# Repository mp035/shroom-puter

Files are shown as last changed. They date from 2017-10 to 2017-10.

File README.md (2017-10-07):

# shroom-puter
A climate controller for a peltier cooled fruting chamber for mushrooms and other cultures.

This is a personal project so it is not as polished as it could be.

It is based on a Nucleo STM32 Nucleo L031-K6 development board (RS Components part# 9173781)  Other suppliers can be found on [octopart](https://octopart.com/search?q=NUCLEO-L031)

The temperature and humidity sensor is an SHT10.  I found that only the soil temperature and humidity sensors would handle the high humidity environment present inside the chamber.  I got mine on ebay, similar to this one: [Link to eBay page](http://www.ebay.com.au/itm/1-PCS-Temperature-Humidity-Sensor-Soil-sensor-with-SHT10-Sensor-Probe-NEW-/222600539398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)

The LCD is a Nokia 3310/5510 on a breakout board similar to this one: [Link to eBay page](http://www.ebay.com.au/itm/1PCS-84-48-84x48-LCD-Module-White-Backlight-Adapter-PCB-for-Nokia-5110-Arduino-/152131918753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)

The PCB layout is done in Eagle.  I have a newer version in KiCad in the works, but the firmware has not yet been altered to work with the new design.

The sofware is developed with System Workbench for STM32 (sw4stm32) you can use the on-board debugger on the Nucleo to program the firmware.

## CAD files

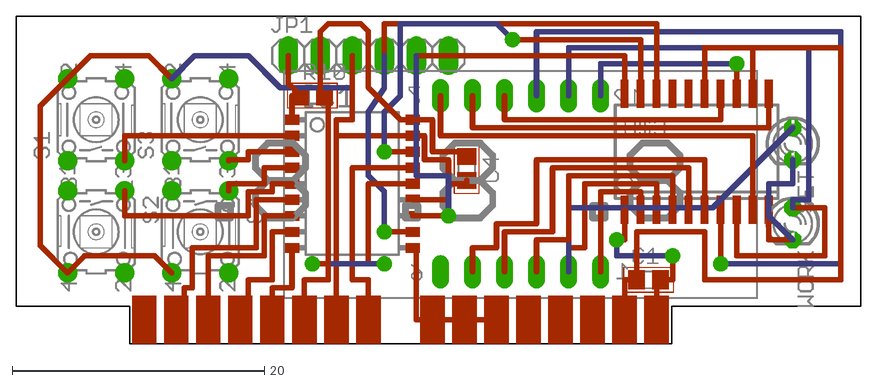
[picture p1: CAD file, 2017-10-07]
eagle_pcb/temperature_controller.dxf
67.0 x 26.0

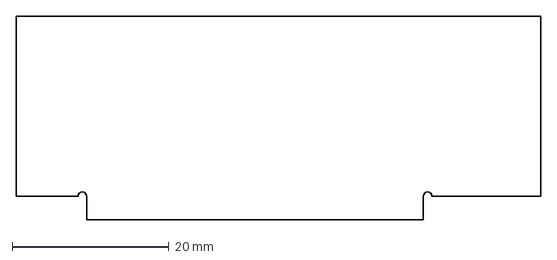
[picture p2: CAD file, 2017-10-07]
eagle_pcb/temperature_controller_top_outline.dxf
67.0 x 26.0 mm

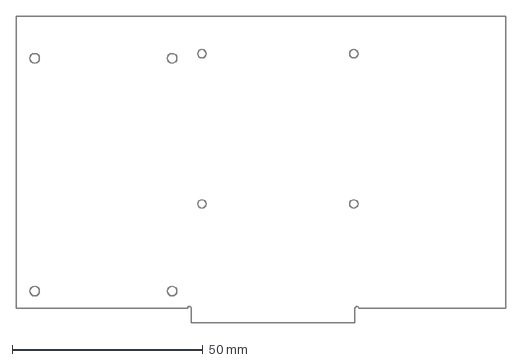
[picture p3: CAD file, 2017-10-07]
eagle_pcb/climate_control_outline.dxf
128.2 x 80.4 mm

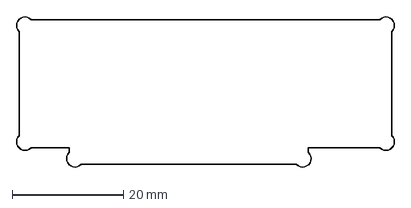
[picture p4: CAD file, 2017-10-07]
eagle_pcb/temperature_controller_top_pocket.dxf
68.2 x 27.2 mm

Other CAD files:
eagle_pcb/.AppleDouble/temperature_controller.dxf
eagle_pcb/.AppleDouble/temperature_controller_top_outline.dxf
eagle_pcb/.AppleDouble/climate_control.dxf
eagle_pcb/.AppleDouble/temperature_controller_top_pocket.dxf
eagle_pcb/.AppleDouble/temperature_controller_bottom_pocket.dxf
eagle_pcb/.AppleDouble/climate_control_outline.dxf

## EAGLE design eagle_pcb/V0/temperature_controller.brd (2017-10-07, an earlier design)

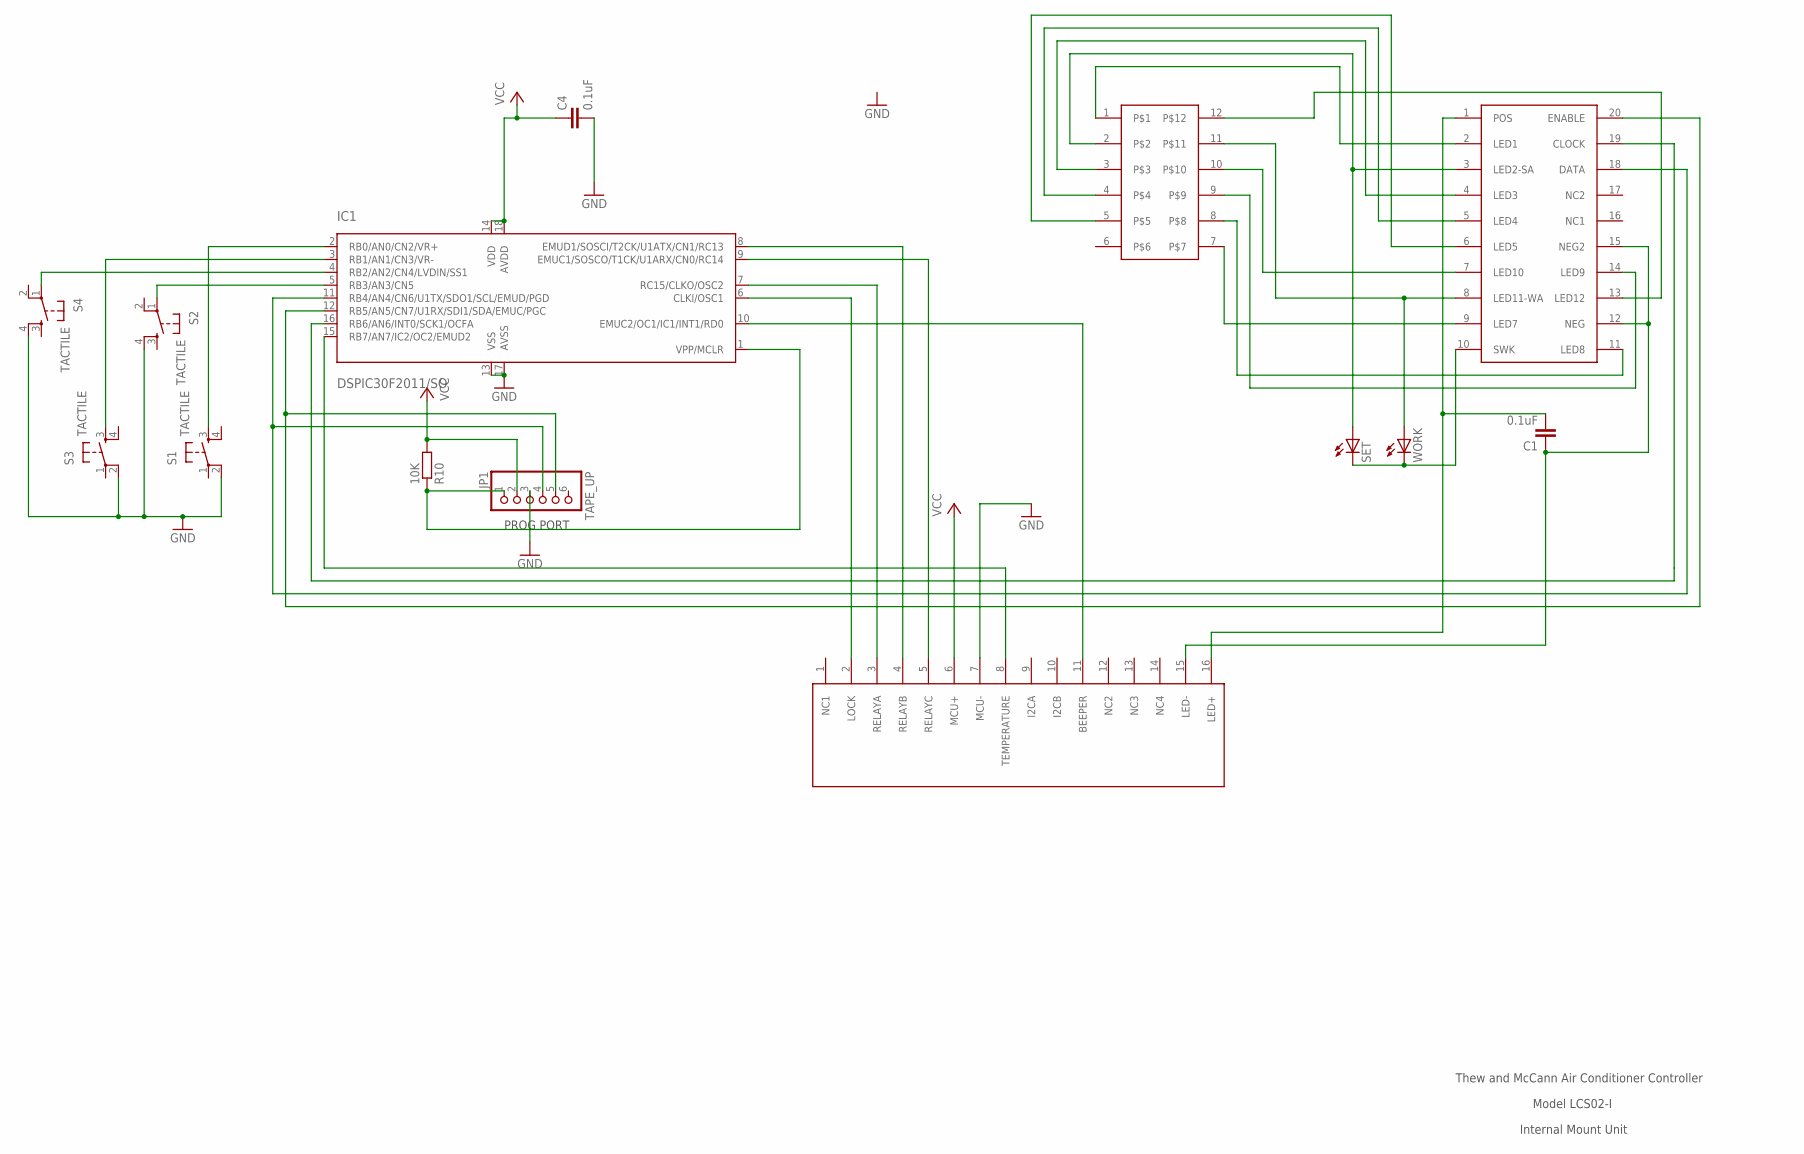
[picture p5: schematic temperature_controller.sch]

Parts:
C1, C4: 0.1uF; C0805
IC1: DSPIC30F2011/SO; SO-18W
JP1: TAPE_UP; 1X06
R10: 10K; R0805
S1, S2, S3, S4: TACTILE
SET: LED3MM
U$1: 3_DIGIT_LED
U$2: WILLHI_EDGE
U$3: 3_DIGIT_DRIVER; SO20W
WORK: LED3MM

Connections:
GND: C4.2, IC1.13 (VSS), IC1.17 (AVSS), JP1.3, S1.2 (P1), S2.4 (S1), S3.2 (P1), S4.4 (S1), U$2.7 (MCU-)
unnamed: U$1.1, U$3.2 (LED1)
unnamed: IC1.4 (RB2/AN2/CN4/LVDIN/SS1), S4.1
unnamed: SET.A, U$1.2, U$3.3 (LED2-SA)
unnamed: U$1.3, U$3.4 (LED3)
unnamed: U$1.4, U$3.5 (LED4)
unnamed: U$1.5, U$3.6 (LED5)
unnamed: U$1.10, U$3.7 (LED10)
unnamed: U$1.11, U$3.8 (LED11-WA), WORK.A
unnamed: U$1.7, U$3.9 (LED7)
unnamed: U$1.9, U$3.14 (LED9)
unnamed: U$1.8, U$3.11 (LED8)
unnamed: SET.K (C), U$3.10 (SWK), WORK.K (C)
unnamed: U$1.12, U$3.13 (LED12)
unnamed: IC1.11 (RB4/AN4/CN6/U1TX/SDO1/SCL/EMUD/PGD), JP1.4, U$3.18 (DATA)
unnamed: IC1.5 (RB3/AN3/CN5), S2.1
unnamed: IC1.16 (RB6/AN6/INT0/SCK1/OCFA), U$3.19 (CLOCK)
unnamed: IC1.7 (RC15/CLKO/OSC2), U$2.3 (RELAYA)
unnamed: IC1.15 (RB7/AN7/IC2/OC2/EMUD2), U$2.8 (TEMPERATURE)
unnamed: C1.2, U$2.16 (LED+), U$3.1 (POS)
unnamed: IC1.1 (VPP/MCLR), JP1.1, R10.1
unnamed: C1.1, U$2.15 (LED-), U$3.12 (NEG), U$3.15 (NEG2)
unnamed: IC1.8 (EMUD1/SOSCI/T2CK/U1ATX/CN1/RC13), U$2.4 (RELAYB)
unnamed: IC1.6 (CLKI/OSC1), U$2.2 (LOCK)
unnamed: IC1.9 (EMUC1/SOSCO/T1CK/U1ARX/CN0/RC14), U$2.5 (RELAYC)
unnamed: IC1.10 (EMUC2/OC1/IC1/INT1/RD0), U$2.11 (BEEPER)
unnamed: IC1.3 (RB1/AN1/CN3/VR-), S3.3 (S)
unnamed: IC1.12 (RB5/AN5/CN7/U1RX/SDI1/SDA/EMUC/PGC), JP1.5, U$3.20 (ENABLE)
unnamed: IC1.2 (RB0/AN0/CN2/VR+), S1.3 (S)
VCC: C4.1, IC1.14 (VDD), IC1.18 (AVDD), JP1.2, R10.2, U$2.6 (MCU+)

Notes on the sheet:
PROG PORT
Thew and McCann Air Conditioner Controller
Model LCS02-I
Internal Mount Unit

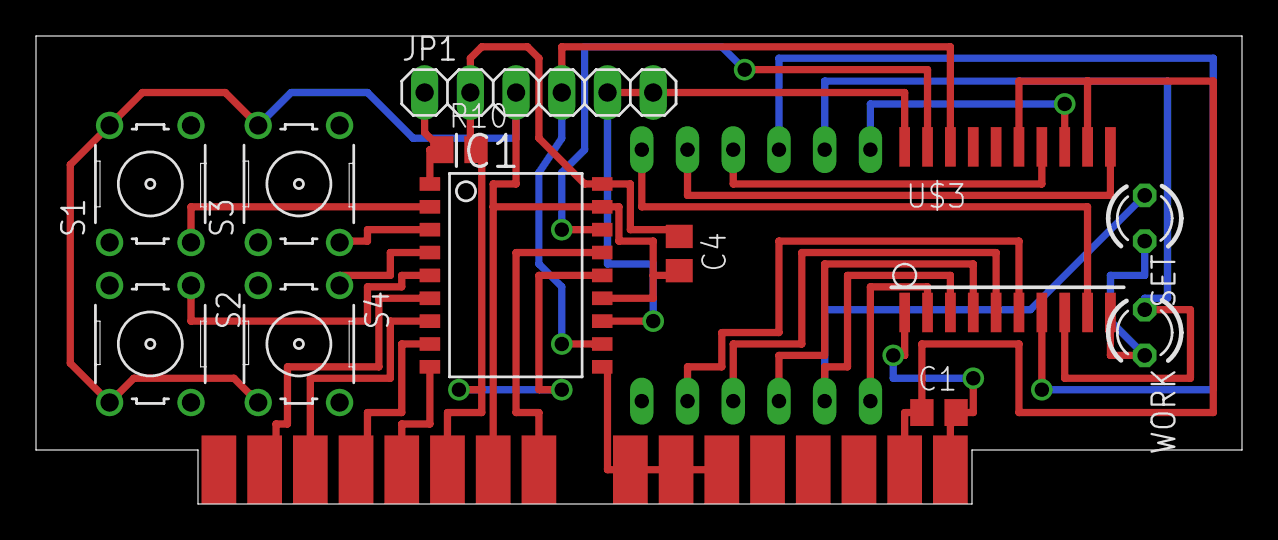
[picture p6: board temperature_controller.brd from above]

Board: 2 copper layers, 67.0 x 26.0 mm, 14 parts (1 on the bottom side), 30 nets.

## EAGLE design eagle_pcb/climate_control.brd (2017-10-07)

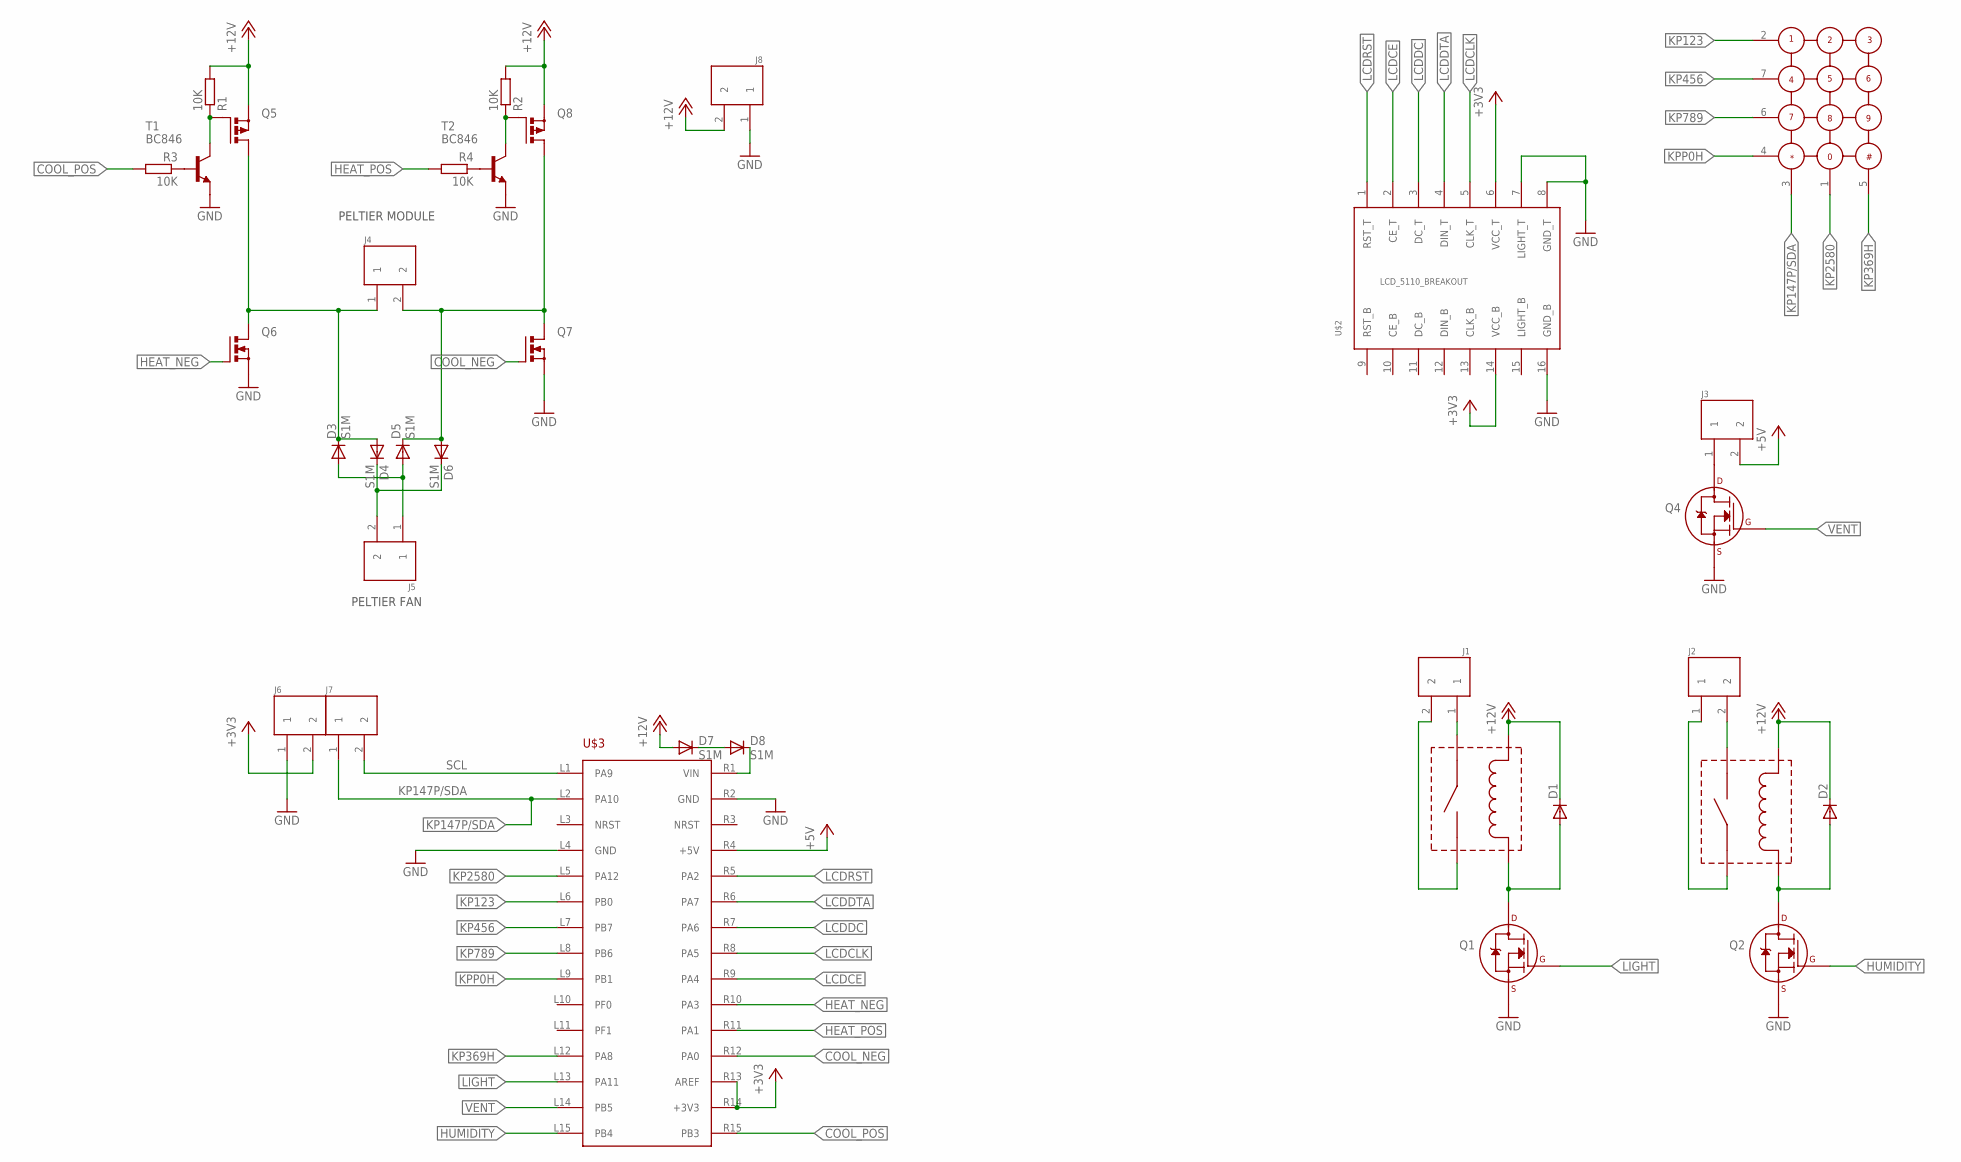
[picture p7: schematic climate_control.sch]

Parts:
D1, D2: DIODE-DO-214AC; DO-214AC
D3, D4, D5, D6, D7, D8: S1M; SMA
J1, J2, J3, J4, J5, J6, J7, J8: TERMINAL_PCB_508_X2; TERMINAL_PCB_508_PITCH
Q1, Q2, Q4: 2N7000_TO92; TO-92
Q5, Q8: PMOSFET_PTO220BV; TO220BV
Q6, Q7: PMOSFET_NTO220BV; TO220BV
R1, R2, R3, R4: 10K; R0805
T1, T2: BC846; SOT23
U$1: KEYPAD12
U$2: LCD_5110_BREAKOUT
U$3: NUCLEO_F031; NUCLEO_30
U$5, U$7: RELAY_JZC-33F

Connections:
+3V3: J6.2, U$2.6 (VCC_T), U$2.14 (VCC_B), U$3.R13 (AREF), U$3.R14 (+3V3)
+5V: J3.2, U$3.R4 (+5V)
+12V: D1.C, D2.C, D7.A, J8.2, Q5.S, Q8.S, R1.2, R2.2, U$5.COIL1, U$7.COIL2
COOL_NEG: Q7.G, U$3.R12 (PA0)
COOL_POS: R3.2, U$3.R15 (PB3)
GND: J6.1, J8.1, Q1.1 (S), Q2.1 (S), Q4.1 (S), Q6.S, Q7.S, T1.2 (E), T2.2 (E), U$2.7 (LIGHT_T), U$2.8 (GND_T), U$2.16 (GND_B), U$3.L4 (GND), U$3.R2 (GND)
HEAT_NEG: Q6.G, U$3.R10 (PA3)
HEAT_POS: R4.2, U$3.R11 (PA1)
HUMIDITY: Q2.2 (G), U$3.L15 (PB4)
KP123: U$1.2 (123), U$3.L6 (PB0)
KP147P/SDA: J7.1, U$1.3 (147*), U$3.L2 (PA10)
KP369H: U$1.5 (369#), U$3.L12 (PA8)
KP456: U$1.7 (456), U$3.L7 (PB7)
KP789: U$1.6 (789), U$3.L8 (PB6)
KP2580: U$1.1 (2580), U$3.L5 (PA12)
KPP0H: U$1.4 (*0#), U$3.L9 (PB1)
LCDCE: U$2.2 (CE_T), U$3.R9 (PA4)
LCDCLK: U$2.5 (CLK_T), U$3.R8 (PA5)
LCDDC: U$2.3 (DC_T), U$3.R7 (PA6)
LCDDTA: U$2.4 (DIN_T), U$3.R6 (PA7)
LCDRST: U$2.1 (RST_T), U$3.R5 (PA2)
LIGHT: Q1.2 (G), U$3.L13 (PA11)
unnamed: D3.A, D5.A, J5.1
unnamed: D7.C, D8.A
unnamed: D4.C, D6.C, J5.2
unnamed: D3.C, D4.A, J4.1, Q5.D, Q6.D
unnamed: D5.C, D6.A, J4.2, Q7.D, Q8.D
unnamed: Q5.G, R1.1, T1.3 (C)
unnamed: Q8.G, R2.1, T2.3 (C)
unnamed: R3.1, T1.1 (B)
unnamed: R4.1, T2.1 (B)
unnamed: D8.C, U$3.R1 (VIN)
unnamed: D1.A, Q1.3 (D), U$5.COIL2
unnamed: J1.1, U$5.CONTACT1
unnamed: J1.2, U$5.CONTACT2
unnamed: D2.A, Q2.3 (D), U$7.COIL1
unnamed: J2.2, U$7.CONTACT2
unnamed: J2.1, U$7.CONTACT1
unnamed: J3.1, Q4.3 (D)
SCL: J7.2, U$3.L1 (PA9)
VENT: Q4.2 (G), U$3.L14 (PB5)

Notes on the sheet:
PELTIER FAN
PELTIER MODULE

Board: 2 copper layers, 34 parts (1 on the bottom side), 41 nets, no tracks yet.

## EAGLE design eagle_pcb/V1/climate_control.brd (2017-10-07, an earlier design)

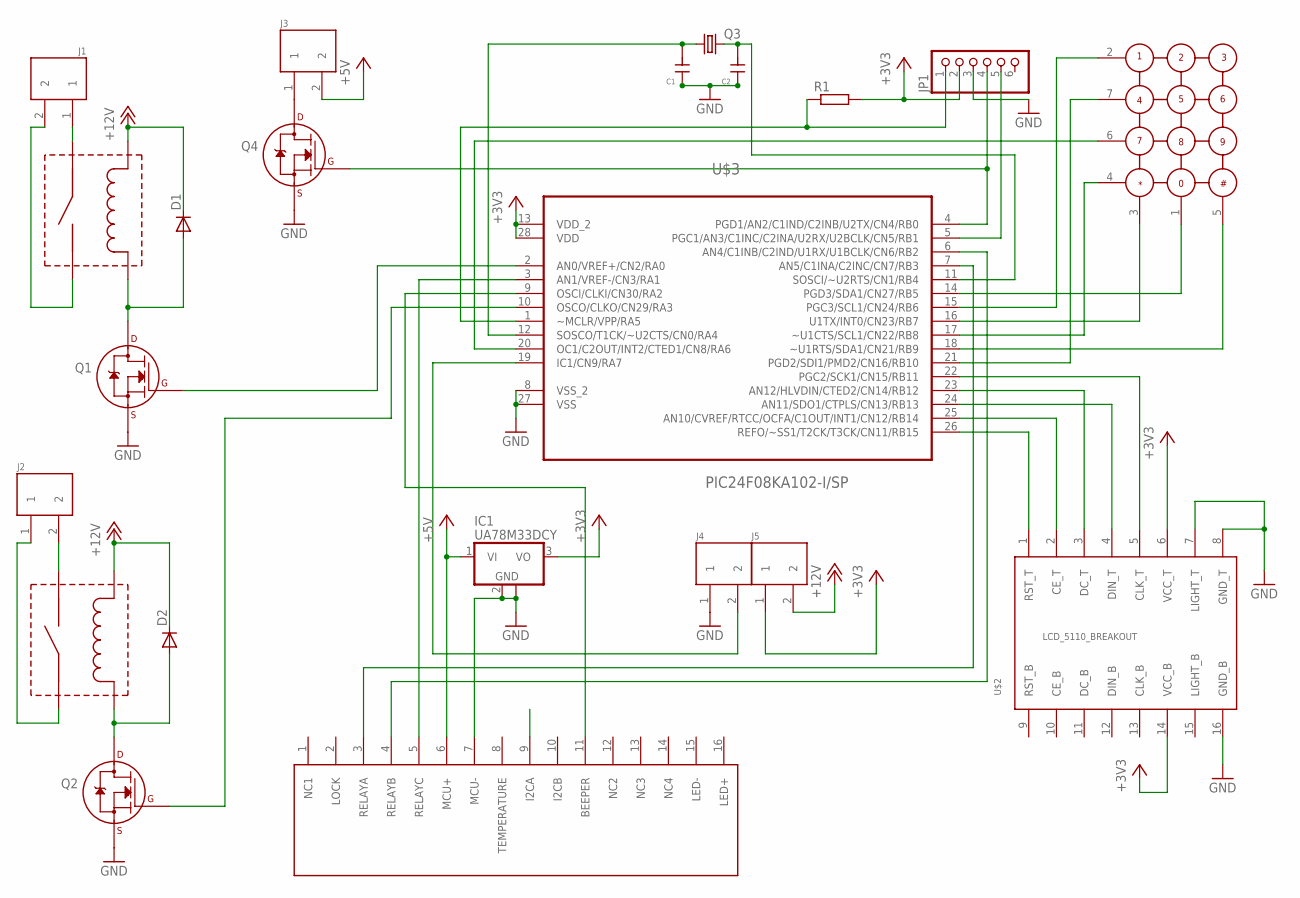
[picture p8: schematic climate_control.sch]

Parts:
C1, C2: DUALCAP
D1, D2: DIODE-DO-214AC; DO-214AC
IC1: UA78M33DCY; SOT223
J1, J2, J3, J4, J5: TERMINAL_PCB_508_X2; TERMINAL_PCB_508_PITCH
JP1: PINHD-1X6; 1X06
Q1, Q2, Q4: 2N7000_TO92; TO-92
Q3: CRYSTALTC38H; TC38H
R1: R-EU_0207/10; 0207/10
U$1: KEYPAD12
U$2: LCD_5110_BREAKOUT
U$3: PIC24F08KA102-I/SP; DIP254P762X533-28
U$4: WILLHI_EDGE
U$5, U$7: RELAY_JZC-33F

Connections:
+3V3: IC1.3 (VO), J5.1, JP1.2, R1.2, U$2.6 (VCC_T), U$2.14 (VCC_B), U$3.13 (VDD_2), U$3.28 (VDD)
+5V: IC1.1 (VI), J3.2, U$4.6 (MCU+)
+12V: D1.C, D2.C, J5.2, U$5.COIL1, U$7.COIL2
GND: C1.P$2, C1.P$3, C2.P$2, C2.P$3, IC1.2 (GND), IC1.4 (GND), J4.1, JP1.3, Q1.1 (S), Q2.1 (S), Q4.1 (S), U$2.7 (LIGHT_T), U$2.8 (GND_T), U$2.16 (GND_B), U$3.8 (VSS_2), U$3.27 (VSS), U$4.7 (MCU-)
unnamed: U$2.4 (DIN_T), U$3.24 (AN11/SDO1/CTPLS/CN13/RB13)
unnamed: U$2.5 (CLK_T), U$3.22 (PGC2/SCK1/CN15/RB11)
unnamed: U$2.3 (DC_T), U$3.23 (AN12/HLVDIN/CTED2/CN14/RB12)
unnamed: U$2.2 (CE_T), U$3.25 (AN10/CVREF/RTCC/OCFA/C1OUT/INT1/CN12/RB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)
unnamed: U$2.1 (RST_T), U$3.26 (REFO/~SS1/T2CK/T3CK/CN11/RB15)
unnamed: U$1.7 (456), U$3.21 (PGD2/SDI1/PMD2/CN16/RB10)
unnamed: U$1.6 (789), U$3.20 (OC1/C2OUT/INT2/CTED1/CN8/RA6)
unnamed: U$1.4 (*0#), U$3.17 (~U1CTS/SCL1/CN22/RB8)
unnamed: U$1.5 (369#), U$3.18 (~U1RTS/SDA1/CN21/RB9)
unnamed: U$1.3 (147*), U$3.16 (U1TX/INT0/CN23/RB7)
unnamed: U$1.2 (123), U$3.15 (PGC3/SCL1/CN24/RB6)
unnamed: U$1.1 (2580), U$3.14 (PGD3/SDA1/CN27/RB5)
unnamed: U$3.9 (OSCI/CLKI/CN30/RA2), U$4.11 (BEEPER)
unnamed: JP1.1, R1.1, U$3.1 (~MCLR/VPP/RA5)
unnamed: U$3.3 (AN1/VREF-/CN3/RA1), U$4.5 (RELAYC)
unnamed: JP1.4, Q4.2 (G), U$3.4 (PGD1/AN2/C1IND/C2INB/U2TX/CN4/RB0)
unnamed: JP1.5, U$3.5 (PGC1/AN3/C1INC/C2INA/U2RX/U2BCLK/CN5/RB1)
unnamed: J4.2, U$3.19 (IC1/CN9/RA7)
unnamed: U$3.6 (AN4/C1INB/C2IND/U1RX/U1BCLK/CN6/RB2), U$4.4 (RELAYB)
unnamed: U$3.7 (AN5/C1INA/C2INC/CN7/RB3), U$4.3 (RELAYA)
unnamed: D1.A, Q1.3 (D), U$5.COIL2
unnamed: J1.1, U$5.CONTACT1
unnamed: J1.2, U$5.CONTACT2
unnamed: D2.A, Q2.3 (D), U$7.COIL1
unnamed: J2.2, U$7.CONTACT2
unnamed: J2.1, U$7.CONTACT1
unnamed: Q1.2 (G), U$3.2 (AN0/VREF+/CN2/RA0)
unnamed: Q2.2 (G), U$3.10 (OSCO/CLKO/CN29/RA3)
unnamed: C1.P$1, Q3.1, U$3.12 (SOSCO/T1CK/~U2CTS/CN0/RA4)
unnamed: C2.P$1, Q3.2, U$3.11 (SOSCI/~U2RTS/CN1/RB4)
unnamed: J3.1, Q4.3 (D)

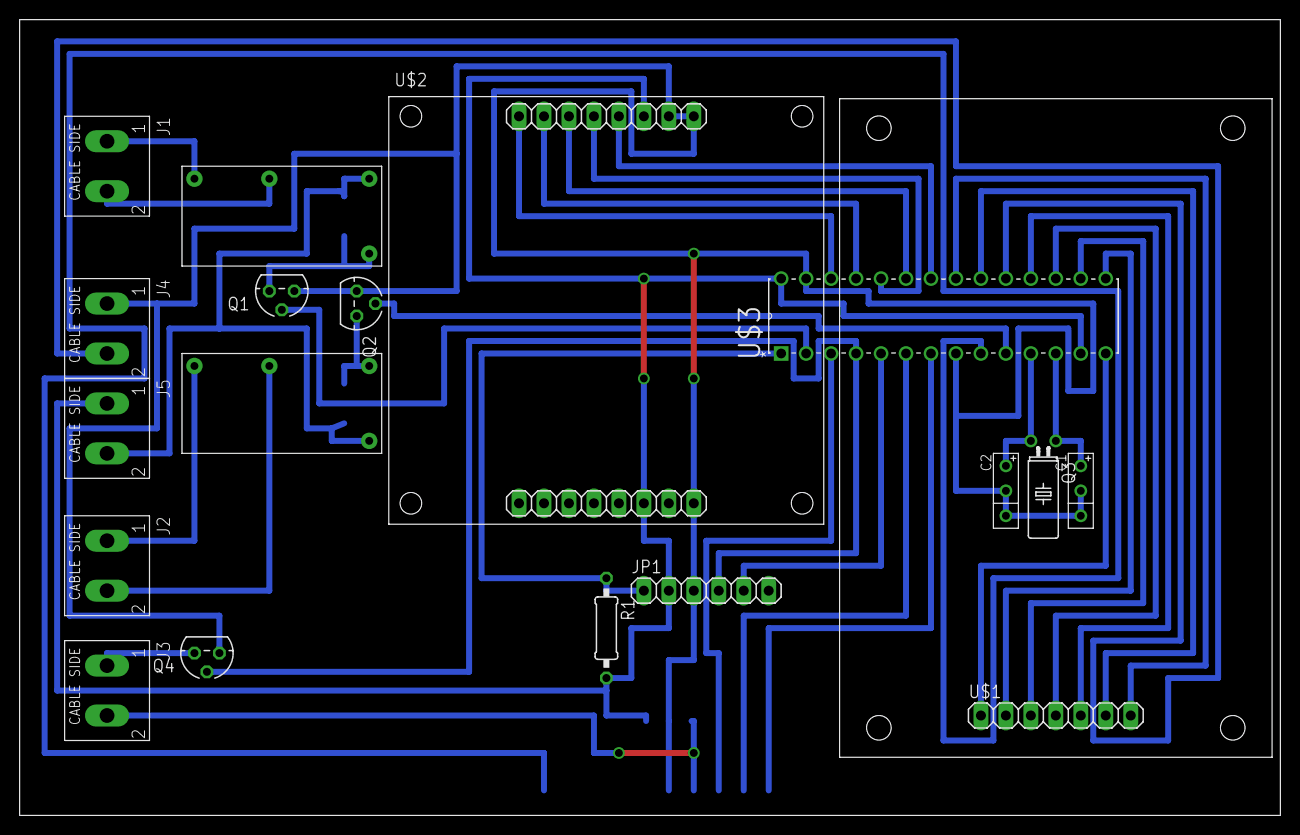
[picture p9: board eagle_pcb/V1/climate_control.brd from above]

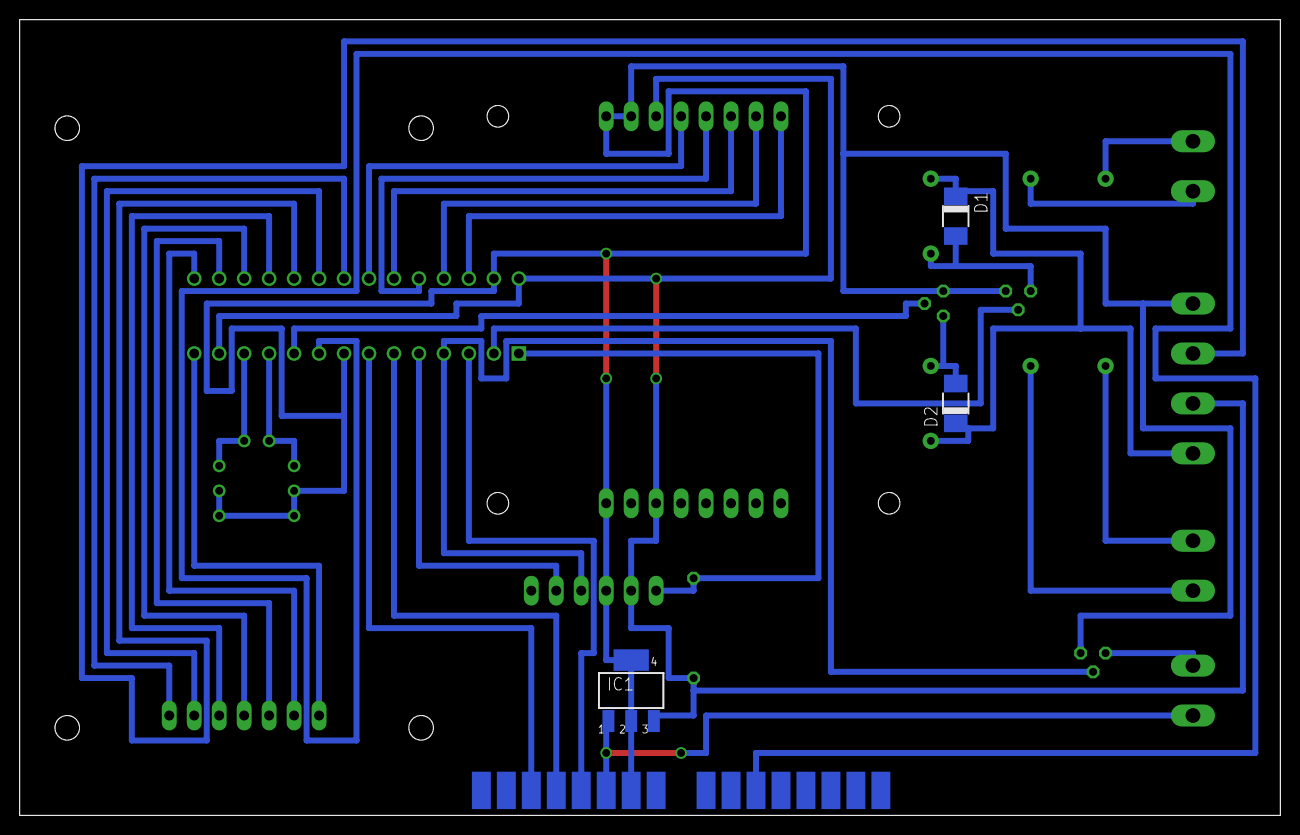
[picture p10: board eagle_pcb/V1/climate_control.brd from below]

Board: 2 copper layers, 128.2 x 81.0 mm, 22 parts (4 on the bottom side), 35 nets.

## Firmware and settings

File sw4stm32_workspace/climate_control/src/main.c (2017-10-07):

/**
  ******************************************************************************
  * @file    main.c
  * @author  Ac6
  * @version V1.0
  * @date    01-December-2013
  * @brief   Default main function.
  ******************************************************************************
*/


//#include <eeprom.h>
#include <stdint.h>
#include <stdbool.h>
#include <stdlib.h>
#include "stm32l0xx.h"
//#include "stm32l0xx_nucleo_32.h"
#include "gpio.h"
#include "widgets.h"
#include "eeprom.h"
#include "sht10.h"
#include "lcd.h"
#include "rtc.h"
#include "keypad.h"
#include "print.h"
#include "systick.h"
#include "sht10.h"
			

extern volatile uint32_t timer16_0_counter;

static const uint8_t water[34] = {16,16,     0,0,0,0,0,192,240,248,254,240,192,0,0,0,0,0,0,0,0,0,31,63,127,127,127,112,57,31,0,0,0,0,};
static const uint8_t cool[34] = {16,16,     0,72,140,16,96,164,72,126,72,164,96,16,140,72,0,0,1,37,99,17,13,75,36,252,36,75,13,17,99,37,1,0,};
static const uint8_t light_on[34] = {16,16,    0,0,0,112,140,2,33,65,33,65,33,2,140,112,0,0,0,0,0,0,1,2,126,213,212,213,126,2,1,0,0,0,};
static const uint8_t fan[34] = {16,16,    0,0,240,12,198,194,217,93,61,193,194,198,12,240,0,0,0,0,0,131,134,133,137,248,248,137,133,134,131,0,0,0,};
static const uint8_t heat[34] = {16,16,    0,128,130,4,192,240,240,248,251,248,240,240,192,4,130,128,0,0,32,16,1,7,7,15,111,15,7,7,1,16,32,0,};
static const uint8_t light_off[34] = {16,16,    0,0,0,248,204,2,3,129,193,225,115,58,158,254,7,3,0,96,112,56,31,14,127,243,241,240,124,14,3,0,0,0,};
static const uint8_t cross_black[34] = {16,16,0x02, 0x05, 0x0a, 0x14, 0x28, 0x50, 0xa0, 0x40, 0x40, 0xa0, 0x50, 0x28, 0x14, 0x0a, 0x05, 0x02, 0x40, 0xa0, 0x50, 0x28, 0x14, 0x0a, 0x05, 0x02, 0x02, 0x05, 0x0a, 0x14, 0x28, 0x50, 0xa0, 0x40};
static const uint8_t cross_white[34] = {16,16,0xfe, 0xfd, 0xfb, 0xf7, 0xef, 0xdf, 0xbf, 0x7f, 0x7f, 0xbf, 0xdf, 0xef, 0xf7, 0xfb, 0xfd, 0xfe, 0x7f, 0xbf, 0xdf, 0xef, 0xf7, 0xfb, 0xfd, 0xfe, 0xfe, 0xfd, 0xfb, 0xf7, 0xef, 0xdf, 0xbf, 0x7f};

typedef enum
{
    APPL_DRAW_HOME
    ,APPL_HOME
    ,APPL_DRAW_DOOR_OPEN
    ,APPL_DOOR_OPEN
    ,APPL_DRAW_MENU
    ,APPL_MENU
    ,APPL_DRAW_TIME_SET
    ,APPL_TIME_SET
    ,APPL_DRAW_TEMP_MENU
    ,APPL_TEMP_MENU
    ,APPL_DRAW_TEMP_SET
    ,APPL_TEMP_SET
    ,APPL_DRAW_TEMP_BAND_SET
    ,APPL_TEMP_BAND_SET
    ,APPL_DRAW_RH_MENU
    ,APPL_RH_MENU
    ,APPL_DRAW_HUMIDITY_SET
    ,APPL_HUMIDITY_SET
    ,APPL_DRAW_HUMIDITY_BAND_SET
    ,APPL_HUMIDITY_BAND_SET
    ,APPL_DRAW_LIGHT_MENU
    ,APPL_LIGHT_MENU
    ,APPL_DRAW_LIGHT_ON_SET
    ,APPL_LIGHT_ON_SET
    ,APPL_DRAW_LIGHT_OFF_SET
    ,APPL_LIGHT_OFF_SET
    ,APPL_DRAW_FAN_MENU
    ,APPL_FAN_MENU
    ,APPL_DRAW_FAN_RUN_SET
    ,APPL_FAN_RUN_SET
    ,APPL_DRAW_FAN_OFF_SET
    ,APPL_FAN_OFF_SET
    ,APPL_DRAW_DISABLE_MENU
    ,APPL_DISABLE_MENU
} app_state_e;

int32_t door_open_time_in_seconds;
int16_t temperatureset = 250;
int16_t temperatureband = 10;
int16_t humidityset = 950;
int16_t humidityband = 10;
int16_t startlight = 600;
int16_t stoplight = 1800;
volatile int16_t fanrunminutes = 15;
volatile int16_t fanidleminutes = 2;
uint64_t fancounter = 0;
uint32_t next_screen_update = 0;
uint32_t next_app_gate = 0;

// addresses for persistent variables
#define ADDR_temperatureset 0
#define ADDR_temperatureband 1
#define ADDR_humidityset 2
#define ADDR_humidityband 3
#define ADDR_startlight 4
#define ADDR_stoplight 5
#define ADDR_fanrunminutes 6
#define ADDR_fanidleminutes 7

// some macros which automatically handle the eeprom adresses of the variables
#define AUTO_EE_READ_INIT(variable, default_value) variable = eeprom_read(ADDR_##variable);\
													if (variable == 0) variable = default_value;\

#define AUTO_EE_WRITE(variable) eeprom_write(ADDR_##variable, variable);
#define AUTO_EE_READ(variable) variable = eeprom_read(ADDR_##variable);

// flags to hold state of each aspect
bool disable_humidity = false, disable_light = false, disable_vent = false;
volatile bool disable_temp = false;

// internal flags to hold status for display
uint8_t output_status = 0;
#define STATUS_HEATING 0x01
#define STATUS_COOLING 0x02
#define STATUS_HUMIDIFYING 0x04
#define STATUS_LIGHTING 0x08
#define STATUS_VENTILATING 0x10

//relays to control functions
#define HUMIDITY(x) GPIO_WRITE(B, 4, x)
#define LIGHTING(x) GPIO_WRITE(A, 11, x)
#define VENTILATION(x) GPIO_WRITE(B, 5, x)
//#define HEATING(x) peltier_heating = x;
//#define COOLING(x) peltier_cooling = x;
/*
#define HEATING(x) heating(x)
void heating(uint16_t x)
{
	GPIO_CLR(B,3);// cooling pos
	GPIO_CLR(A,0);// cooling neg
	if (x)
	{
		GPIO_SET(A,1);// heating pos
		GPIO_SET(A,3);// heating neg
	}
	else
	{
		GPIO_CLR(A,1);// heating pos
		GPIO_CLR(A,3);// heating neg
	}
}

#define COOLING(x) cooling(x)
void cooling(uint16_t x)
{
	GPIO_CLR(A,1);// heating pos
	GPIO_CLR(A,3);// heating neg
	if (x)
	{
		GPIO_SET(B,3);// cooling pos
		GPIO_SET(A,0);// cooling neg
	}
	else
	{
		GPIO_CLR(B,3);// cooling pos
		GPIO_CLR(A,0);// cooling neg
	}
}
*/


void setup_decimal_widget(int16_t numeric_value, widget_t *widget)
{
    widget->widget_type = NUMCTRL;
    widget->xpos = 21;
    widget->ypos = 16;
    widget->digits = 3;
    if (numeric_value > 999) numeric_value = 999;
    widget->numeric_value = numeric_value;
    widget->decimal_position = 2;
    widget->cursor_position = 0;
    widget->return_value = WIDGET_DRAW_CANCEL;
    widget->zero_pad = 1;
}

void setup_3digit_integer_widget(int16_t numeric_value, widget_t *widget)
{
    widget->widget_type = NUMCTRL;
    widget->xpos = 21;
    widget->ypos = 16;
    widget->digits = 3;
    if (numeric_value > 999) numeric_value = 999;
    widget->numeric_value = numeric_value;
    widget->decimal_position = 0;
    widget->cursor_position = 0;
    widget->return_value = WIDGET_DRAW_CANCEL;
    widget->zero_pad = 1;
}

void setup_time_widget(int16_t time_value, widget_t *widget)
{
    widget->widget_type = TIMECTRL;
    widget->xpos = 21;
    widget->ypos = 16;
    if (time_value > 2359) time_value = 2359;
    widget->numeric_value = time_value;
    widget->cursor_position = 0;
    widget->return_value = WIDGET_DRAW_CANCEL;
}

void draw_setting_screen(char* title1, char* title2, widget_t *widget, char *units)
{
    LCDClear();
    LCDString(title1);
    int16_t posx,posy;
    if (title2 == 0)
    {
        LCDString("            ");
        posx = 49;
        posy = 16;
        widget->xpos = 24;
        widget->ypos = posy;
    }
    else
    {
        LCDString(title2);
        posx = 49;
        posy = 24;
        widget->xpos = 24;
        widget->ypos = posy;
    }

    gotoXY(posx,posy);

    LCDString(units);

    gotoXY(0,32);
    if (widget->return_value == WIDGET_DRAW_CANCEL)
    {
        LCDString(" *          # ");
        LCDString("CANCEL    NEXT");
    }
    else if (widget->return_value == WIDGET_DRAW_CONFIRM)
    {
        LCDString(" *          # ");
        LCDString(" BACK      OK ");
    }
    else
    {
        LCDString(" *          # ");
        LCDString(" BACK    NEXT ");
    }

    draw_widget(widget);

    LCDRefresh(0);


}

void handle_settings_keys(uint8_t keyvalue, int16_t* temperature_parameter, uint16_t parameter_eeprom_address, app_state_e *applicaton_state, widget_t * widget, app_state_e draw_previous_screen_state, app_state_e draw_screen_state)
{
    if (keyvalue) // 100ms debounce
    {
        pass_key_to_widget(keyvalue, widget);
        switch(widget->return_value)
        {
        case WIDGET_CANCEL:
            *applicaton_state = draw_previous_screen_state;
            break;
        case WIDGET_CONFIRM:
            *temperature_parameter = widget->numeric_value;
            *applicaton_state = draw_previous_screen_state;
			eeprom_write(parameter_eeprom_address, *temperature_parameter);
            break;
        default:
            *applicaton_state = draw_screen_state;
        }
    }
}

int16_t main (void)
{
    /* Initialize IO ports and peripherals */
    setup(1);

	// load eeprom values
	AUTO_EE_READ_INIT(temperatureset, 250);
	AUTO_EE_READ_INIT(temperatureband, 10);
	AUTO_EE_READ_INIT(humidityset, 950);
	AUTO_EE_READ_INIT(humidityband, 10);
	AUTO_EE_READ_INIT(startlight, 600);
	AUTO_EE_READ_INIT(stoplight, 1800);
	AUTO_EE_READ_INIT(fanrunminutes, 15);
	AUTO_EE_READ_INIT(fanidleminutes, 105);

    uint16_t trh_error = 0;
    app_state_e application_state = APPL_DRAW_HOME;

    widget_t numwidget;

	uint8_t keyvalue;
	HUMIDITY(0);
	VENTILATION(0);
	LIGHTING(0);
	//HEATING(0);
	//COOLING(0);

    while (1)
    {
        if (next_screen_update <= GetSystickMs())
{
        	next_screen_update += 5000;// check references to door_open_time_in_seconds if changing this value.
            trh_error = read_temp_rh_sensor();
            if (application_state == APPL_HOME)
                application_state = APPL_DRAW_HOME; // force home screen refresh if required.
            if (application_state == APPL_DOOR_OPEN)
            {
                door_open_time_in_seconds -= 5; // this should line up with the number of seconds that this loop is called.
                if (door_open_time_in_seconds <= 0)
                {
                    application_state = APPL_DRAW_HOME;
                }

                VENTILATION(0);
                HUMIDITY(0);
                //HEATING(0);
                //COOLING(0);
                LIGHTING(1);
            }
            else
            {
            	if ((GetSystickMs() - fancounter) < (fanrunminutes * 60000))
            	{
            		if (disable_vent)
            		{
            			output_status &= ~(STATUS_VENTILATING);
            			VENTILATION(0);
            		}
            		else
            		{
            			output_status |= STATUS_VENTILATING;
            			VENTILATION(1);
            		}
            	}
            	else if ((GetSystickMs() - fancounter)
            			< ((fanrunminutes + fanidleminutes) * 60000))
            	{
            		output_status &= ~(STATUS_VENTILATING);
            		VENTILATION(0);
            	}
            	else // fancounter has rolled over
            	{
            		fancounter += (fanrunminutes + fanidleminutes) * 60000;
            		output_status &= ~(STATUS_VENTILATING);
            		VENTILATION(0);
            	}

            	if ((humidity > humidityset) || disable_humidity)
            	{
            		output_status &= ~(STATUS_HUMIDIFYING);
            		HUMIDITY(0);
            	}
            	else if (humidity < (humidityset - humidityband))
            	{
            		output_status |= STATUS_HUMIDIFYING;
            		HUMIDITY(1);
            	}

            	// if the humidity set point is > 90% and humidity is above the setpoint then use the fan to lower humidity
            	if (
            			(humidityset > 900)
						&& (humidity > (humidityset + humidityband))
						&& ! disable_vent
            	)
            	{
            		output_status |= STATUS_VENTILATING;
            		VENTILATION(1);
            	}

            	uint16_t ltemp;
            	ltemp = hour * 100 + minute;
            	if (startlight < stoplight) // we are lighting through the day
            	{
            		if (ltemp < stoplight && ltemp >= startlight && ! disable_light)
            		{
            			output_status |= STATUS_LIGHTING;
            			LIGHTING(1);
            		}
            		else
            		{
            			output_status &= ~(STATUS_LIGHTING);
            			LIGHTING(0);
            		}
            	}
            	else if (startlight > stoplight) // we are lighting through midnight
            	{
            		if (ltemp >= stoplight && ltemp < startlight && ! disable_light)
            		{
            			output_status &= ~(STATUS_LIGHTING);
            			LIGHTING(0);
            		}
            		else
            		{
            			output_status |= STATUS_LIGHTING;
            			LIGHTING(1);
            		}
            	}
            	else // startlight == stoplight
            	{
            		output_status &= ~(STATUS_LIGHTING);
            		LIGHTING(0);
            	}

            	// Temperature control algorithms.
            	int32_t temp_duty = temperatureset - temperature;
            	temp_duty = temp_duty * 100 / temperatureband;

            	if (temp_duty > 100) temp_duty = 100;
            	if (temp_duty < -100) temp_duty = -100;

            	if(temp_duty < 0)
            	{
            		output_status |= STATUS_COOLING;
            		output_status &= ~STATUS_HEATING;
            	}
            	else if (temp_duty > 0)
            	{
            		output_status |= STATUS_HEATING;
            		output_status &= ~STATUS_COOLING;
            	}
            	else
            	{
            		output_status &= ~STATUS_COOLING;
            		output_status &= ~STATUS_HEATING;
            	}
            	target_duty_setting = temp_duty;
            }
        }

        /* wait until delay time has elapsed */
        keyvalue = scan_for_keycode();
        while (next_app_gate > GetSystickMs())
        {
            // ******************************* IDLE LOOP *********************************
            if (keyvalue == 0)
                keyvalue = scan_for_keycode(); // keep looking for keypresses while idle, but only if none have already been registered.
            LCDService();
        }
        next_app_gate += 125;
        ReadRtc(); // update time values

        // ************************ THIS IS THE MAIN STATE MACHINE FOR THE MENU/DISPLAY SYSTEM ***********************
        uint16_t temptime;
        switch (application_state)
        {
        case APPL_DRAW_HOME:
            LCDClear();
            if (trh_error)
            {
                LCDString("   SENSOR          ERROR    ");
            }
            else
            {
                // alternate between peltier duty and measured temp.
                // screen refreshes every 5 seconds, so work with that for now.
                static uint8_t temppingpong;
                temppingpong++;
                //if (temppingpong % 2)
                //{
                LCDString("TEMP:");
                	printshort(temperature / 10, 3, 0);
                	LCDCharacter('.');
                	printshort(temperature % 10, 1, 1);
                	LCDCharacter(0x80);
                	LCDCharacter('C');
                	LCDCharacter(' ');
                	LCDCharacter(' ');
                //}
                //else
                //{
                LCDString("DUTY:");
                	LCDCharacter(' ');
                	if (peltier_duty_setting < 0)
                	{
                		LCDCharacter('-');
                	}
                	else
                	{
                		LCDCharacter(' ');
                	}
                	printshort(abs(peltier_duty_setting), 3, 0);
                	LCDCharacter('%');
                	LCDCharacter(' ');
                	LCDCharacter(' ');
                	LCDCharacter(' ');
                //}

                LCDString(" R/H:");
                printshort(humidity / 10, 3, 0);
                LCDCharacter('.');
                printshort(humidity % 10, 1, 1);
                LCDCharacter('%');
                LCDCharacter(' ');
                LCDCharacter(' ');
                LCDCharacter(' ');
                LCDString("TIME: ");
                printshort(hour, 2, 1);
                LCDCharacter(':');
                printshort(minute, 2, 1);

            }

            static uint8_t counter = 255;
            counter++;

            if (disable_humidity)
            {
            	LCDBitmap(water, 6, 32);
            	LCDOverlay(cross_black,6,32,1);
            	LCDOverlay(cross_white,6,32,0);
            }
            else if (output_status & STATUS_HUMIDIFYING) LCDBitmap(water, 6, 32);

            if (disable_temp)
            {
            	if (counter & 1) LCDBitmap(cool, 25, 32);
            	else LCDBitmap(heat,25,32);
            	LCDOverlay(cross_black,25,32,1);
            	LCDOverlay(cross_white,25,32,0);

            }
            else if (output_status & STATUS_COOLING) LCDBitmap(cool, 25, 32);

            if (disable_temp)
            {
            	if (counter & 1) LCDBitmap(cool, 25, 32);
				else LCDBitmap(heat,25,32);
				LCDOverlay(cross_black,25,32,1);
				LCDOverlay(cross_white,25,32,0);
            }
            else if (output_status & STATUS_HEATING) LCDBitmap(heat, 25, 32);

            if (disable_light)
            {
            	LCDBitmap(light_on, 44, 32);
				LCDOverlay(cross_black,44,32,1);
				LCDOverlay(cross_white,44,32,0);
            }
            else if (output_status & STATUS_LIGHTING)LCDBitmap(light_on, 44, 32);

            if (disable_vent)
            {
            	LCDBitmap(fan, 63, 32);
				LCDOverlay(cross_black,63,32,1);
				LCDOverlay(cross_white,63,32,0);
            }
            else if (output_status & STATUS_VENTILATING) LCDBitmap(fan, 63, 32);

            LCDRefresh(0);
            application_state = APPL_HOME;
            break;
        case APPL_HOME:
            if (keyvalue) // 100ms debounce
            {
                if (keyvalue == '*')
                {
                    application_state = APPL_DRAW_DOOR_OPEN;
                }
                else if (keyvalue == '#')
                {
                	application_state = APPL_DRAW_DISABLE_MENU;
                }
                else
                {
                    application_state = APPL_DRAW_MENU;
                }
            }

            break;
        case APPL_DRAW_DOOR_OPEN:
            LCDClear();
            LCDString("  DOOR OPEN   ");
            LCDString(" MODE ACTIVE. ");
            LCDString("PRESS ANY KEY ");
            LCDString(" TO RETURN TO ");
            LCDString(" NORMAL MODE  ");
            LCDString("**************");

            LCDRefresh(0);
            door_open_time_in_seconds = (15 * 60); // the door open state will automatically abort after 15 minutes
            application_state = APPL_DOOR_OPEN;
            break;
        case APPL_DOOR_OPEN:
            if (keyvalue)
            // 100ms debounce
            {
                application_state = APPL_DRAW_HOME;
            }
            break;
        case APPL_DRAW_MENU:
            LCDClear();
            LCDString("1-SET TIME    ");
            LCDString("2-SET TEMP    ");
            LCDString("3-SET R/H     ");
            LCDString("4-SET LIGHT   ");
            LCDString("5-SET FAN     ");
            LCDString("*-EXIT MENU   ");

            //LCDClear();
            //LCDString("1-Light On  ");
            //LCDString("2-Set Time  ");
            //LCDString("3-Set Temp  ");
            //LCDString("4-Set R/H   ");
            //LCDString("5-Set Light ");
            //LCDString("6-Set Fan   ");
            LCDRefresh(0);
            application_state = APPL_MENU;
            break;
        case APPL_MENU:
            switch (keyvalue)
            // 100ms debounce
            {
            case '1': // SET TIME
                setup_time_widget((hour * 100 + minute), &numwidget);
                application_state = APPL_DRAW_TIME_SET;
                break;
            case '2': // SET TEMP
                application_state = APPL_DRAW_TEMP_MENU;
                break;
            case '3': // SET RH
                application_state = APPL_DRAW_RH_MENU;
                break;
            case '4': // SET LIGHT
                application_state = APPL_DRAW_LIGHT_MENU;
                break;
            case '5': // SET FAN
                application_state = APPL_DRAW_FAN_MENU;
                break;
            case '*': // EXIT MENU
                application_state = APPL_DRAW_HOME;
                break;
            }
            break;
        case APPL_DRAW_TIME_SET:
            draw_setting_screen(" CURRENT TIME ", " (24HR TIME)  ", &numwidget,
                    "");
            application_state = APPL_TIME_SET;
            break;
        case APPL_TIME_SET:
            // the setting of the time is a special case because we do not have a single variable to hold the time value, and
            // interrupts must be disabled to change the time value outside the isr, so we use a temporary variable and transfer
            // the values if it changes.

            temptime = 0xFFFF;
            handle_settings_keys(keyvalue, (int16_t*)&temptime, 0xFFFF, &application_state,
                    &numwidget, APPL_DRAW_MENU, APPL_DRAW_TIME_SET);
            if (temptime != 0xFFFF)
            {
				// FIXME: We need to set the time on STM32
            	//uint16_t temp;
				//temp = SRbits.IPL;
				//SRbits.IPL = 0b111;
            	SetRtc(temptime/100, temptime%100, 0, 1,1,1,0);
                //hour = temptime / 100;
                //minute = temptime % 100;
                //second = 0;

				//SRbits.IPL = temp;

            }
            break;
        case APPL_DRAW_TEMP_MENU:
            LCDClear();
            LCDString("1-TEMPERATURE ");
            LCDString("  SET POINT   ");
            LCDString("2-TEMPERATURE ");
            LCDString("  BAND        ");
            LCDString("#-LAST MENU   ");
            LCDString("*-EXIT MENU   ");
            LCDRefresh(0);
            application_state = APPL_TEMP_MENU;
            break;
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

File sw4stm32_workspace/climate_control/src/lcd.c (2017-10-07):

/*
 * lcd.c
 *
 *  Created on: 26/03/2014
 *      Author: mark
 */
#include <stm32l0xx.h>
#include "main.h"
#include "lcd.h"
#include <stdint.h>
#include "gpio.h"
#include "spi.h"
#include "systick.h"


#define OUTPUT 1
#define INPUT 0
#define LCD_COMMAND 0
#define LCD_DATA  1
#define LCD_SETDATA() GPIO_SET(A,6)
#define LCD_SETCONTROL() GPIO_CLR(A,6)
#define LCD_CS_SET_DIRECTION() GPIO_AS_OUTPUT(A,4)
#define LCD_DC_SET_DIRECTION() GPIO_AS_OUTPUT(A,6)
#define LCD_RST_SET_DIRECTION() GPIO_AS_OUTPUT(A,2)
#define LCD_ASSERT_RESET() GPIO_CLR(A,2)
#define LCD_RELEASE_RESET() GPIO_SET(A,2)
#define LCD_DELAY() lcd_delay()
volatile uint8_t spireadtmp;
#define WRITE_TO_SPI(x) spireadtmp = (*(__IO uint8_t *)&SPI1->DR); (*(__IO uint8_t *)&SPI1->DR = x)
#define WAIT_FOR_SPI_COMPLETION() while( SPI1->SR & SPI_SR_BSY )
#define SPI_TRANSMIT_NOT_FULL() (SPI1->SR & SPI_SR_TXE)
#define LCD_DESELECT_CHIP() GPIO_SET(A,4)// this is used for manual frame sync, define it as nothing if your SPI module self-syncs.
#define LCD_SELECT_CHIP() GPIO_CLR(A,4) // this is used for manual frame sync, define it as nothing if your SPI module self-syncs.

void lcd_delay(void)
{

	DelayMs(10);
}
#define LCD_X 84
#define LCD_Y 48

//This table contains the hex values that represent pixels
//for a font that is 5 pixels wide and 8 pixels high
static const uint8_t ASCII[][5] = {
  {0x00, 0x00, 0x00, 0x00, 0x00} // 20
  ,{0x00, 0x00, 0x5f, 0x00, 0x00} // 21 !
  ,{0x00, 0x07, 0x00, 0x07, 0x00} // 22 "
  ,{0x14, 0x7f, 0x14, 0x7f, 0x14} // 23 #
  ,{0x24, 0x2a, 0x7f, 0x2a, 0x12} // 24 $
  ,{0x23, 0x13, 0x08, 0x64, 0x62} // 25 %
  ,{0x36, 0x49, 0x55, 0x22, 0x50} // 26 &
  ,{0x00, 0x05, 0x03, 0x00, 0x00} // 27 '
  ,{0x00, 0x1c, 0x22, 0x41, 0x00} // 28 (
  ,{0x00, 0x41, 0x22, 0x1c, 0x00} // 29 )
  ,{0x14, 0x08, 0x3e, 0x08, 0x14} // 2a *
  ,{0x08, 0x08, 0x3e, 0x08, 0x08} // 2b +
  ,{0x00, 0x50, 0x30, 0x00, 0x00} // 2c ,
  ,{0x08, 0x08, 0x08, 0x08, 0x08} // 2d -
  ,{0x00, 0x60, 0x60, 0x00, 0x00} // 2e .
  ,{0x20, 0x10, 0x08, 0x04, 0x02} // 2f /
  ,{0x3e, 0x51, 0x49, 0x45, 0x3e} // 30 0
  ,{0x00, 0x42, 0x7f, 0x40, 0x00} // 31 1
  ,{0x42, 0x61, 0x51, 0x49, 0x46} // 32 2
  ,{0x21, 0x41, 0x45, 0x4b, 0x31} // 33 3
  ,{0x18, 0x14, 0x12, 0x7f, 0x10} // 34 4
  ,{0x27, 0x45, 0x45, 0x45, 0x39} // 35 5
  ,{0x3c, 0x4a, 0x49, 0x49, 0x30} // 36 6
  ,{0x01, 0x71, 0x09, 0x05, 0x03} // 37 7
  ,{0x36, 0x49, 0x49, 0x49, 0x36} // 38 8
  ,{0x06, 0x49, 0x49, 0x29, 0x1e} // 39 9
  ,{0x00, 0x36, 0x36, 0x00, 0x00} // 3a :
  ,{0x00, 0x56, 0x36, 0x00, 0x00} // 3b ;
  ,{0x08, 0x14, 0x22, 0x41, 0x00} // 3c <
  ,{0x14, 0x14, 0x14, 0x14, 0x14} // 3d =
  ,{0x00, 0x41, 0x22, 0x14, 0x08} // 3e >
  ,{0x02, 0x01, 0x51, 0x09, 0x06} // 3f ?
  ,{0x32, 0x49, 0x79, 0x41, 0x3e} // 40 @
  ,{0x7e, 0x11, 0x11, 0x11, 0x7e} // 41 A
  ,{0x7f, 0x49, 0x49, 0x49, 0x36} // 42 B
  ,{0x3e, 0x41, 0x41, 0x41, 0x22} // 43 C
  ,{0x7f, 0x41, 0x41, 0x22, 0x1c} // 44 D
  ,{0x7f, 0x49, 0x49, 0x49, 0x41} // 45 E
  ,{0x7f, 0x09, 0x09, 0x09, 0x01} // 46 F
  ,{0x3e, 0x41, 0x49, 0x49, 0x7a} // 47 G
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
  ,{0x02, 0x04, 0x08, 0x10, 0x20} // 5c \ //make sure the slash is not at the end of the line as it will form a multi-line comment
  ,{0x00, 0x41, 0x41, 0x7f, 0x00} // 5d ]
  ,{0x04, 0x02, 0x01, 0x02, 0x04} // 5e ^
  ,{0x40, 0x40, 0x40, 0x40, 0x40} // 5f _
  ,{0x00, 0x01, 0x02, 0x04, 0x00} // 60 `
  ,{0x20, 0x54, 0x54, 0x54, 0x78} // 61 a
  ,{0x7f, 0x48, 0x44, 0x44, 0x38} // 62 b
  ,{0x38, 0x44, 0x44, 0x44, 0x20} // 63 c
  ,{0x38, 0x44, 0x44, 0x48, 0x7f} // 64 d
  ,{0x38, 0x54, 0x54, 0x54, 0x18} // 65 e
  ,{0x08, 0x7e, 0x09, 0x01, 0x02} // 66 f
  ,{0x0c, 0x52, 0x52, 0x52, 0x3e} // 67 g
  ,{0x7f, 0x08, 0x04, 0x04, 0x78} // 68 h
  ,{0x00, 0x44, 0x7d, 0x40, 0x00} // 69 i
  ,{0x20, 0x40, 0x44, 0x3d, 0x00} // 6a j
  ,{0x7f, 0x10, 0x28, 0x44, 0x00} // 6b k
  ,{0x00, 0x41, 0x7f, 0x40, 0x00} // 6c l
  ,{0x7c, 0x04, 0x18, 0x04, 0x78} // 6d m
  ,{0x7c, 0x08, 0x04, 0x04, 0x78} // 6e n
  ,{0x38, 0x44, 0x44, 0x44, 0x38} // 6f o
  ,{0x7c, 0x14, 0x14, 0x14, 0x08} // 70 p
  ,{0x08, 0x14, 0x14, 0x18, 0x7c} // 71 q
  ,{0x7c, 0x08, 0x04, 0x04, 0x08} // 72 r
  ,{0x48, 0x54, 0x54, 0x54, 0x20} // 73 s
  ,{0x04, 0x3f, 0x44, 0x40, 0x20} // 74 t
  ,{0x3c, 0x40, 0x40, 0x20, 0x7c} // 75 u
  ,{0x1c, 0x20, 0x40, 0x20, 0x1c} // 76 v
  ,{0x3c, 0x40, 0x30, 0x40, 0x3c} // 77 w
  ,{0x44, 0x28, 0x10, 0x28, 0x44} // 78 x
  ,{0x0c, 0x50, 0x50, 0x50, 0x3c} // 79 y
  ,{0x44, 0x64, 0x54, 0x4c, 0x44} // 7a z
  ,{0x00, 0x08, 0x36, 0x41, 0x00} // 7b {
  ,{0x00, 0x00, 0x7f, 0x00, 0x00} // 7c |
  ,{0x00, 0x41, 0x36, 0x08, 0x00} // 7d }
  ,{0x10, 0x08, 0x08, 0x10, 0x08} // 7e ~
  ,{0x78, 0x46, 0x41, 0x46, 0x78} // 7f DEL
  ,{0b00000110, 0b00001001, 0b00001001, 0b00000110, 0x00} // mp035: the degree symbol as 0x80.
};

#ifdef USE_SCREEN_BUFFER
uint8_t lcd_buffer[84][6]; // screen buffer for lcd
uint8_t lcd_col = 0, lcd_row = 0, buffer_written = 1, refresh_in_progress = 0, service_row = 0, service_col = 0;
#define LCDX 84
#define LCDY 6 //(bytes not pixels)

void LCDWrite(int command_or_data, int data)
{
    if(command_or_data)
    {
        while(refresh_in_progress) // don't alter data until any pending refresh is complete.
        {
            LCDService();
        }

        buffer_written = 0;
        lcd_buffer[lcd_col++][lcd_row] = data;
        if (lcd_col >= LCDX)
        {
            lcd_col = 0;
            lcd_row ++;
            if (lcd_row >=LCDY)
            {
                lcd_row = 0;
            }
        }
    }
    else
    {
        if (! buffer_written) //if the buffer has not been written when a command is sent, it is good practice to write it out so that the expected image is shown.
        {
            LCDRefresh(1);
        }
		WAIT_FOR_SPI_COMPLETION(); // because we need to sync the D/C pin, we need to wait for the SSP controller to finish the last transmission.
		LCD_DESELECT_CHIP();
		LCD_SETCONTROL();
		LCD_SELECT_CHIP();
        WRITE_TO_SPI(data);
    }
}
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

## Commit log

2017-10-07 Original commit working firmware, Eagle PCB design.
    [climate_control.brd, climate_control.dxf, climate_control.sch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]
2017-10-07 Fix embedded git in sw4stm32 workspace
    [i2c_master.c]
2017-12-07 Fixed problem with temperature control algorithm that causes short operation of heater and cooler within band.
